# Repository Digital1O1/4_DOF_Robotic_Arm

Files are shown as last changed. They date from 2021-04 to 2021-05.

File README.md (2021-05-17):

# Intention Of 4_DOF_Robotic_Arm Project
1. Take gyroscopic/magnetometer/accelerometer data from an MPU_9250 to calculate the Yaw/Pitch/Roll
2. Use three NRF24l01 Radio frequency development boards to wirelessly transmit data from one microcontroller (Teensy 4) to two other microcontrollers (Wedmos D1 | Arduino Nano)
3. Display the calulated Yaw/Pitch/Roll values that are being transmitted/recieved on their perspective SH1106 OLED display (Recieving/Transmitting)
4. Use one microcontroller that's recieving the transmitted data to control a 3-d printed, 4 Degree of Freedom robotic arm. 



## Bill of Materials (BOM)
1. (2) microcontrollers of your choice. (3) were used (Teensy 4/Arduino Nano/ Wedmos D1) in this instance for reasons explained later in this repo.
3. (2) or (3) NRF24l01 radio frequency development boards
5. A BUNCH of male-female wires
6. (3) 10uF or 100 uF electrolytic capacitors
7. (2) SG-90 servo motors
8. (2) SH1106 OLED displays
9. (1) Push button

# In-depth Explantion of Project
- The user is prompted through the Arduino serial monitor or terminal of their choice if they want to calibrate the MPU_9250. 
    - If the user enters '1' in the serial monitor, the calibration procedure will initiate. 
    - If the user enters '2', they can skip the calibration process completely.
- The MPU_9250 gyroscopic/magnetometer/accelerometer data is sent via __SPI__ to the Teensy 4 in order to calculate the pitch/yaw/roll 
- The calculated values are then displayed on an SH1106 OLED display connected via __I2C__ on the Teensy 4 
- The same calculated values are then transmitted through the nrf24l01 to an Arduino Nano and an Wedmos D1 microcontroller as shown in the figure below.



- The Arduino Nano recieves the transmitted data from the Teensy 4 in order to control the 4-DOF robotic as shown in the screenshot below

 

- The Wedmos D1 displays the recieved data on it's own SH1106 OLED display to give reassurnace that the transmitted data is being recieved from the Teensy 4.

## Kalman Filter
What’s a Kalman Filter?

An algorithm that estimates an unknown variable based on the measurements given over time.

Why use a Kalman Filter?

- The Kalman filter was used to reduce the noise from the gyroscopic/accelerometer/magnetometer data to allow the yaw/pitch/roll angles to be calculated as accurately as possible.

- Kalman filters are also typically used with drones to determine their orientation during flight.

- KEEP IN MIND, the values used for the Kalman filter have NOT been fine tuned’ yet since the majority of the time spent on this project was focused on other aspects of this project; but the values will be fine tuned at a later date.

# What's With All The Folders In The Repo?

Here's a quick run-down 

- I2C_Scanner
  - Used for troubleshooting peripherals that use the I2C communication protocol/bus
  - Peripherals like OLED displays use I2C
  - The 'I2C_Scanner' can be used to determine the address of the OLED display, or any peripheral using I2C.

- NRF Folder
  - Contains all NRF24l01 code
  - Hello World 
    - One microcontroller transmits 'Hello World' while the other microcontroller recieves it and displays it on the serial monitor
  - Transmit_Array | Transmit_Struct
    - As the name implies, the transmitted data can be sent two ways. As an array, or as a struct. In reference to this project, the array method was used
  - ackPayload
    - Two way communication between two microcontrollers
    - To elaborate further :
      - One microcontroller transmits data
      - The other recieves it and sends an 'Acknowledgement' back to the transmitting microcontroller that data was recieved
  
  - Robotic_Arm_V3_NRF_Mesh
    -  Teensy_Transmit_IMU_Data
        - Transmit only the gryo/accel/magometer data to the recieving microcontrollers (Wedmos D1/ Nano)
    - Teensy_Transmitter
      - Gives user the option to calibrate the MPU_9250 or to skip the calibration process
      - Calculate yaw/pitch/roll
      - Display yaw/pitch/roll data on SH1106 OLED display
      - Transmit yaw/pitch/roll datat to Wedmos/Nano microcontrollers
    - Nano_Recieve_Robotic_Arm
      - Recieves transmitted data from Teensy
      - Microcontroller responsible for controlling Robotic Arm
    - Wedmos_Recieve_Robotic_Arm
      - Recieves transmitted data
      - Display transmitted data on SH1106 OLED display

# Why Use Two Microcontrollers to Recieve the Transmitted Data?

The Arduino Nano/Uno has only 32 KB of on-board Flash memory.

When the Servo,RF,and OLED libraries were included in the Arduino Nano/Uno sketch/code, the majority of the Flash memory (~97%) was used which lead to the microcontroller to become unstable and would periodically crash. 

When the same steps were repeated with the Wedmos D1, the RF and OLED libraries together would work fine. 

However when the Servo libraries were included in the sketch/code, the watchdog timer was triggered for some reason and the program wouldn't run.

So rather than troubleshooting why the watchdog timer was being triggered, I took the easy way out of the entire situation and just had the Wedmos D1 display the data being recieved, while the Nano was being used to control the robotic arm and would display the transmitted data via the serial monitor.

# FAQ

- Is the Wedmos D1 needed?
  - Honestly, not really. As mentioned earlier, the sole purpose of the Wedmos D1 was to display the transmitted data from the Teensy.
  - A person really only needs the Teensy (Or a similar development board that has a clock speed greater than 80 Mhz) and the Arduino Uno/Nano to run everything

- Will you re-visit and troubleshoot why the Watchdog timer is being triggered on the Wedmos D1 when the servo library is inlucded with the RF and OLED libraries?
  - It'll depend on the amount of free time I have on my hands since I'm not working on projects in my Github Repository full time

- How will I print out the STL files needed for the Robotic Arm?
  - Contact your local library. Most of them nowadays have a "Maker Space" and SHOULD have 3d-printers that the public can use.

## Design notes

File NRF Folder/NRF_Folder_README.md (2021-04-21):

# Purpose of this folder

To ensure the NRF boards are communicating with one another, upload the sketches/C++ code in the 'Hello World' folder

The other two folders serve as a starting point to send multiple values (floats, ints, ect.) from one microcontroller to another using the NRF2401 RF boards

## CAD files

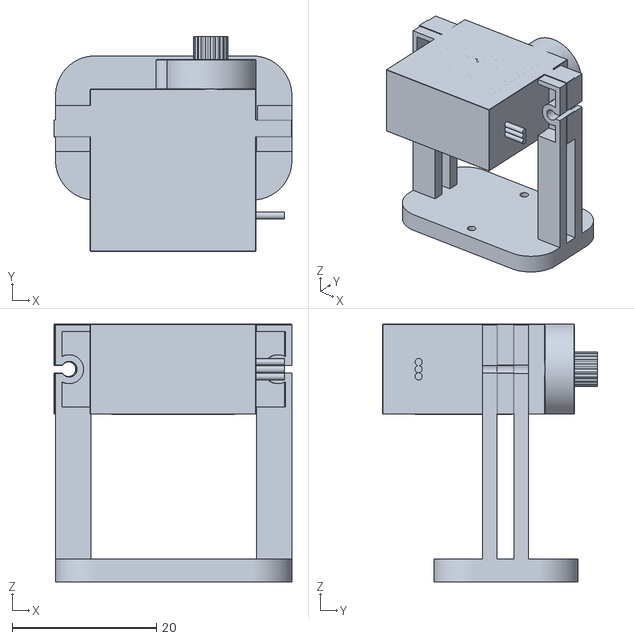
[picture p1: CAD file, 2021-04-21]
STL_Files/Vertical base.stl
33.0 x 29.8 x 35.8

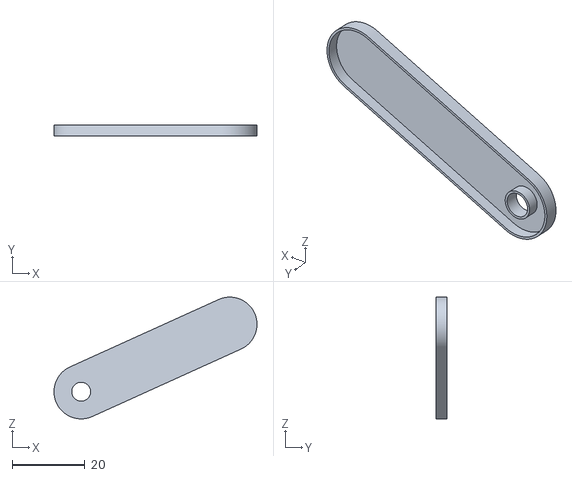
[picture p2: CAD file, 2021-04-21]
STL_Files/Extension Arm.stl
56.0 x 3.00 x 33.6

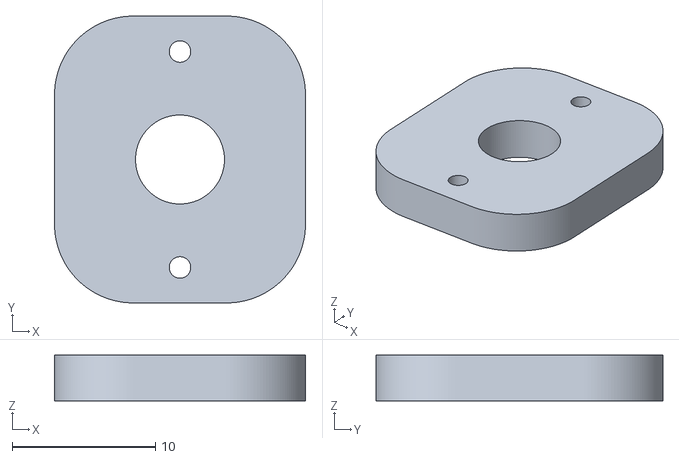
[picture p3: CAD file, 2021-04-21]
STL_Files/Horiztonal base.stl
17.5 x 20.0 x 3.20

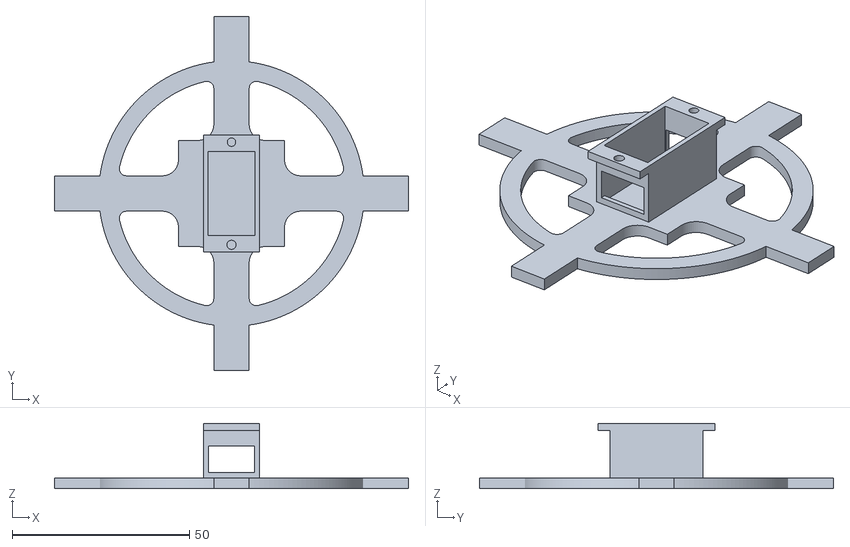
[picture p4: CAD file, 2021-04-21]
STL_Files/Arm_Base.stl
100.0 x 100.0 x 18.5

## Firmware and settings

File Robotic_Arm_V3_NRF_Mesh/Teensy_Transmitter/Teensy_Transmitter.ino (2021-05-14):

/*
   OLED Display using I2C communication BUS

   If using Teensy 4
   SCL = Pin 19
   SDA = Pin 18

*/
#include "MPU9250.h"
#include <Servo.h>
#include "U8g2lib.h"
#include <Wire.h>
#include <nRF24L01.h>
#include <RF24.h>
#include <SPI.h>

#define CE_PIN  7
#define CSN_PIN 8
#define NANO 0
#define WEDMOS 1

U8G2_SH1106_128X64_NONAME_F_HW_I2C OLED(U8G2_R0, /* reset=*/U8X8_PIN_NONE);
MPU9250 IMU(SPI, 10);
Servo x_servo, y_servo;

//---------------------- Variables ----------------------//
const int buttonPin = 2;         // the number of the pushbutton pin
int buttonState = 0;         // variable for reading the pushbutton status
int status, gyro_Calibration_Status,
    accel_Calibration_Status, magn_Calibration_Status,
    map_X, map_Y = 0;
static const float R = 50;                            // Noise covariance (Should be 10) | Higher R --> Filters more, but slower
static const float H = 1.00;                          // Measurement map scalar
static const float Q = 10;                            // Initial estimated covariance
float aX, aY, aZ, gX, gY, gZ, K, P, U_hat_gX, U_hat_gY, U_hat_gZ, U_hat_aX, U_hat_aY, U_hat_aZ, U_hat_mX, U_hat_mY, U_hat_mZ,
      filtered_gX, filtered_gY, filtered_gZ, filtered_aX, filtered_aY, filtered_aZ, gX_bias, gY_bias, gZ_bias,
      aX_bias, aY_bias, aZ_bias, roll, pitch, heading, set_gX_bias, set_gY_bias, set_gZ_bias,
      hxs, hys, hzs, hxb, hyb, hzb, gxb, gyb, gzb, axb, ayb, azb, axs , ays, azs, mag_x, mag_y, yaw,
      mX, mY, mZ, f_ax, filtered_roll, filtered_pitch, filtered_yaw, filtered_mX, filtered_mY, filtered_mZ,
      filtered_mag_x, filtered_mag_y, U_hat_roll, U_hat_pitch, U_hat_yaw = 0;
float sendData[5];
char display_pitch[20], display_roll[20], display_yaw[20], display_map_X[20], display_map_Y[20];

// NRF Stuff
bool radio_result;
const byte numSlaves = 2;
const byte slaveAddress[numSlaves][5] = {
  // each slave needs a different address
  {'R', 'x', 'A', 'A', 'A'},
  {'R', 'x', 'A', 'A', 'B'}
};
RF24 radio(CE_PIN, CSN_PIN); // Create a Radio
float dataToSend[100];
int ackData[2] = { 0, 0}; // to hold the two values coming from the slave
bool newData = false;
//---------------------- Functions ----------------------//
float K_filter_gyro(float &raw_gX, float &raw_gY, float &raw_gZ, float &filtered_gX, float &filtered_gY, float &filtered_gZ)
{
  K = P * H / (H * P * H + R);                        // Current Kalman gain = 0.36
  U_hat_gX = U_hat_gX + K * (raw_gX - H * U_hat_gX);  // Update Estimated values
  U_hat_gY = U_hat_gY + K * (raw_gY - H * U_hat_gY);
  U_hat_gZ = U_hat_gY + K * (raw_gY - H * U_hat_gY);
  P = (1 - K * H) * P + Q;                            // Update Error in Estimate
  filtered_aX = U_hat_aX;
  filtered_aY = U_hat_aY;
  filtered_aZ = U_hat_aZ;
}

float K_filter_accel(float &raw_aX, float &raw_aY, float &raw_aZ, float &filtered_aX, float &filtered_aY, float &filtered_aZ)
{
  K = P * H / (H * P * H + R);                        // Update Kalman Gain | KG == Large --> error in estimate == LARGE error in measurement == Small | KG == Small --> Error im measurement == Large Error in estimate == Small
  U_hat_aX = U_hat_aX + K * (raw_aX - H * U_hat_aX);  // Update Estimated values
  U_hat_aY = U_hat_aY + K * (raw_aY - H * U_hat_aY);
  U_hat_aZ = U_hat_aZ + K * (raw_aZ - H * U_hat_aZ);
  P = (1 - K * H) * P + Q;                            // Update Error in Estimate

  filtered_aX = U_hat_aX;
  filtered_aY = U_hat_aY;
  filtered_aZ = U_hat_aZ;

}

void read_Sensor()
{
  // Read the sensor
  IMU.readSensor();
  aX = IMU.getAccelX_mss();
  aY = IMU.getAccelY_mss();
  aZ = IMU.getAccelZ_mss();
  gX = IMU.getGyroX_rads();
  gY = IMU.getGyroY_rads();
  gZ = IMU.getGyroZ_rads();
  mX = IMU.getMagX_uT();
  mY = IMU.getMagY_uT();
  mZ = IMU.getMagZ_uT();
}


void K_filter(float &raw_aX, float &raw_aY, float &raw_aZ, float &raw_mX, float &raw_mY, float &raw_mZ, float &raw_gX,
              float &raw_gY, float &raw_gZ, float &filtered_aX, float &filtered_aY, float &filtered_aZ,
              float &filtered_gX, float &filtered_gY, float &filtered_gZ, float &filtered_mX, float &filtered_mY, float &filtered_mZ)
{
  K = P * H / (H * P * H + R);                        // Update Kalman Gain | KG == Large --> error in estimate == LARGE error in measurement == Small | KG == Small --> Error im measurement == Large Error in estimate == Small

  //Accelermotor
  U_hat_aX = U_hat_aX + K * (raw_aX - H * U_hat_aX);  // Update Estimated values
  U_hat_aY = U_hat_aY + K * (raw_aY - H * U_hat_aY);
  U_hat_aZ = U_hat_aZ + K * (raw_aZ - H * U_hat_aZ);

  //Gyroscopic
  U_hat_gX = U_hat_gX + K * (raw_gX - H * U_hat_gX);  // Update Estimated values
  U_hat_gY = U_hat_gY + K * (raw_gY - H * U_hat_gY);
  U_hat_gZ = U_hat_gY + K * (raw_gY - H * U_hat_gY);

  //Mag
  U_hat_mX = U_hat_mX + K * (raw_mX - H * U_hat_mX);  // Update Estimated values
  U_hat_mY = U_hat_mY + K * (raw_mY - H * U_hat_mY);
  U_hat_mZ = U_hat_mY + K * (raw_mY - H * U_hat_mY);
  P = (1 - K * H) * P + Q;

  filtered_aX = U_hat_aX;
  filtered_aY = U_hat_aY;
  filtered_aZ = U_hat_aZ;

  filtered_gX = U_hat_gX;
  filtered_gY = U_hat_gY;
  filtered_gZ = U_hat_gZ;

  filtered_mX = U_hat_mX;
  filtered_mY = U_hat_mY;
  filtered_mZ = U_hat_mZ;
}


void K_filter_pitch_roll(float &raw_roll, float &raw_pitch, float &raw_yaw)
{
  K = P * H / (H * P * H + R);                        // Update Kalman Gain | KG == Large --> error in estimate == LARGE error in measurement == Small | KG == Small --> Error im measurement == Large Error in estimate == Small

  U_hat_roll = U_hat_roll + K * (raw_roll - H * U_hat_roll);  // Update Estimated values
  U_hat_pitch = U_hat_pitch + K * (raw_pitch - H * U_hat_pitch);
  U_hat_yaw = U_hat_yaw + K * (raw_yaw - H * U_hat_yaw);

  P = (1 - K * H) * P + Q;

  filtered_roll = U_hat_roll;
  filtered_pitch = U_hat_pitch;
  filtered_yaw = U_hat_yaw;
}

void plot_serial_data()
{
  Serial.print(roll);  Serial.print(',');
  Serial.print(pitch); Serial.print(',');
  Serial.print(yaw); Serial.print(',');
  Serial.print(filtered_roll); Serial.print(',');
  Serial.print(filtered_pitch); Serial.print(',');
  Serial.println(filtered_yaw);
}
void display_serial_data()
{
  Serial.print("Roll : "); Serial.print(roll);
  Serial.print("\tPitch : "); Serial.print(pitch);
  Serial.print("\tYaw : "); Serial.print(yaw);
  Serial.print("\t Filtered Roll : "); Serial.print(filtered_roll);
  Serial.print("\tFiltered Pitch : "); Serial.print(filtered_pitch);
  Serial.print("\tFiltered Yaw  : "); Serial.println(filtered_yaw);
}
void setup()
{
  // Serial communication
  Serial.begin(115200);

  // Button stuff
  pinMode(buttonPin, INPUT);

  // OLED stuff
  OLED.setI2CAddress(0x3D * 2);
  OLED.begin();
  OLED.setFont(u8g2_font_7x13B_mr);

  // RF stuff
  radio.begin();

  //speed  RF24_250KBPS for 250kbs, RF24_1MBPS for 1Mbps, or RF24_2MBPS for 2Mbps
  radio.setDataRate( RF24_250KBPS );

  //Ack payloads are a handy way to return data back to senders without manually changing the radio modes on both units.
  radio.enableAckPayload();

  /*
     Set the number and delay of retries upon failed submit.
     Syntax : setRetries(delay,count);
     delay How long to wait between each retry, in multiples of 250us, max is 15. 0 means 250us, 15 means 4000us.
     count How many retries before giving up, max 15
  */
  radio.setRetries(3, 5); // delay, count


  Serial.println("-------------[ SERIAL COMMUNICATION ESTABLISHED ]-------------\n");
  Serial.println("-------------[ CHECKING IMU ]-------------\n");

  // Start communication with IMU and estimates/removes gyro bias from sensor data | This has to be first for some reason
  status = IMU.begin();
  if (status < 0)
  {
    Serial.println("IMU initialization unsuccessful");
    Serial.println("Check IMU wiring or try cycling power");
    Serial.print("Status: ");
    Serial.println(status);
    while (1) {}
  }
  else
  {
    Serial.println("-------------[ IMU IS OPERATIONAL ]-------------\n");
    OLED.drawStr(40, 10, "Check");
    OLED.drawStr(40, 30, "Serial");
    OLED.drawStr(40, 50, "Monitor");
    OLED.sendBuffer();  // transfer internal memory to the display
    OLED.clearBuffer(); // clear the internal memory
  }

  Serial.println("Enter '1' to calibrate | Enter '2' to skip calibration");
  while (true)
  {
    buttonState = digitalRead(buttonPin);

    if ((Serial.available() > 0) || (buttonState == HIGH))
    {
      char user_input = Serial.read();
      if (user_input == '1')
        //switch (user_input)
      {
        //case '1':
        {
          // =============================================== CALIBRATION STUFF STARTS HERE =============================================== //

          //---------------------------------------------------- [ CALIBRATE GYRO ] ----------------------------------------------------//
          /*
              -- GYRO --
              The gyro bias is automatically estimated during the begin() function, then removed from sensor measurements
              IMU.calibrateGyro(); --> Will re-estimate gyro bias and remove new bias from future measurements
              NEEDS TO BE STATIONARY
              Function should return POSITIVE value on succcess | NEGATIVE value on failure
          */

          Serial.println("===============================================================================================");
          Serial.println("\nCALIBRATE GYROSCOPE...");

          // Wait for user input
          while (true)
          {
            // Checks serial monitor for incoming data
            if (Serial.available() > 0)
            {
              // If user presses 'ENTER' break out of while loop
              if (Serial.read() == '\n')
              {
                Serial.println("\nPlace IMU sensor on solid surface and DON'T TOUCH IT");
                delay(2000);

                Serial.println("\nCALIBRATION STARTING IN...\n");
                break;
              }
            }
            //Serial.print(".");
            delay(2000);
          }
          // Countdown timer
          for (int i = 5; i > 0; i--)
          {
            Serial.print(i);
            Serial.println("...");
            delay(1000);
          }
          Serial.println("\nCALIBRATION IN PROGRESS");

          if (IMU.calibrateGyro() == true)
          {
            Serial.println("\nCALIBRATION COMPLETE\n");

            // "Grab" bias values
            gxb = IMU.getGyroBiasX_rads();
            gyb = IMU.getGyroBiasY_rads();
            gzb = IMU.getGyroBiasZ_rads();

            // Set bias values
            IMU.setGyroBiasX_rads(gxb);
            IMU.setGyroBiasY_rads(gyb);
            IMU.setGyroBiasZ_rads(gzb);

            // Print out bias values
            Serial.println("---- GYRO BIAS VALUES SET TO ----\n");
            Serial.print("GXB : "); Serial.print(gxb); Serial.print(',');
            Serial.print(" GYB : "); Serial.print(gyb); Serial.print(',');
            Serial.print(" GZB : "); Serial.println(gzb);
          }
          //---------------------------------------------------- [ CALIBRATE ACCELEROMOTOR ] ----------------------------------------------------//

          /*
              -- ACCEL --
              int calibrateAccel() --> estimate bias/scale factor needed to calibrate accelerometer

              Works on one axis at a time, needs to run on all 6 sensor orientation
              After it collects enough sensor data, it'll estimate the bias/scale factor for all three accelerometer channels and apply the corrections to measured data
              Accel calibration needs to be performed ONCE on IMU
              Both get/set functions can be used to retrieve estimated bias/scale factors and use them during future power cycles or operations with IMU
          */
          Serial.println("===============================================================================================\n");
          Serial.println("\n-------------[ CALIBRATING ACCELEROMOTOR ]-------------\n");
          delay(1200);
          Serial.println("Orientate IMU to desiered INITAL position to calibrate all SIX axes\n");
          delay(1200);
          Serial.println("To initiate ACCELEROMOTOR calibration press [ ENTER ]...");
          // Wait for user input
          while (true)
          {
            // Checks serial monitor for incoming data
            if (Serial.available() > 0)
            {
              // If user presses 'ENTER' break out of while loop
              if (Serial.read() == '\n')
              {
                Serial.println("\nCALIBRATION IN PROGRESS...");
                break;
              }
            }
            Serial.print(".");
            delay(1000);

          }
          // This is where the actual calibration takes place. Orientate the IMU sensor in SIX different directions AND MAKE SURE IT'S STABLE
          for (int n = 1; n <= 6; n++)
          {
            Serial.print("\nCurrent calibration iteration(s) : ");
            Serial.print(n); Serial.println(" \\ 6\n");

            // Countdown timer
            for (int i = 5; i > 0; i--)
            {
              Serial.print(i);
              Serial.println("...");
              delay(1000);
            }
            Serial.println("\n-------------[ CALIBRATION IN PROGRESS ]-------------");

            IMU.calibrateAccel();

            Serial.println("\n-------------[ Change IMU posistion ]-------------");
          }
          Serial.println("\n-------------[ Calibrating accelerometer COMPLETE ]-------------\n");


          // Get Scale factor values
          // Scale factors are the ratio between the measured output and the change in the 'sense' input
          // More info about scale factors can be found here : https://www.edn.com/evaluating-inertial-measurement-units/
          axs = IMU.getAccelScaleFactorX();
          ays = IMU.getAccelScaleFactorY();
          azs = IMU.getAccelScaleFactorZ();

          // Biased Factors
          axb = IMU.getAccelBiasX_mss();
          ayb = IMU.getAccelBiasY_mss();
          azb = IMU.getAccelBiasZ_mss();

          // Display scale/bias values
          Serial.println("\n-------------[ SCALE FACTORS ]-------------\n");

          Serial.print("X_Scale Factor : "); Serial.print(axs);
          Serial.print(" Y_Scale Factor : "); Serial.print(ays);
          Serial.print(" Z_Scale Factor : "); Serial.println(azs);

          Serial.println("\n-------------[ BIAS VALUES]-------------\n");

          Serial.print("X_Biased : "); Serial.print(axb);
          Serial.print(" Y_Biased : "); Serial.print(ayb);
          Serial.print(" Z_Biased : "); Serial.println(azb);

          // Store scale/bias values into an array
          const float accelBias[3] = {axb, ayb, azb};
          const float accelFactor[3] = {axs, ays, azs};

          // Set the scale/bias values accordingly
          Serial.println("\n-------------[ IMU VALUES SET TO]-------------\n");
          IMU.setAccelCalX(accelBias[0], accelFactor[0]);
          IMU.setAccelCalY(accelBias[1], accelFactor[1]);
          IMU.setAccelCalZ(accelBias[2], accelFactor[2]);

          // Display
          Serial.print("Ax_Bias : "); Serial.print(accelBias[0]);  Serial.print(" | Ax_Accel : "); Serial.println(accelFactor[0]);
          Serial.print("Ay_Bias : "); Serial.print(accelBias[1]);  Serial.print(" | Ay_Accel : "); Serial.println(accelFactor[1]);
          Serial.print("Az_Bias : "); Serial.print(accelBias[2]);  Serial.print(" | Az_Accel : "); Serial.println(accelFactor[2]);
          delay(3000);

          Serial.println("\n===============================================================================================\n");
          delay(2000);

          //---------------------------------------------------- [ CALIBRATE MAGNETOMETER ] ----------------------------------------------------//

          Serial.println("\nPress [ ENTER ] to calibrate megnetometer...");

          // Calibration won't start until user inputs 'ENTER' in the serial monitor
          while (true)
          {
            // Checks serial monitor for incoming data
            if (Serial.available() > 0)
            {
              // If user presses 'ENTER' break out of while loop
              if (Serial.read() == '\n')
              {
                Serial.println("\n\n-------------[ CALIBRATING MAGNETOMETER WILL TAKE ~60-80 SECONDS TO COMPLETE...]-------------");
                delay(1500);
                Serial.println("\n-------------[ SLOWLY AND CONTINUOUSLY MAKE A FIGURE 8 MOTION DURING CALIBRATION ]-------------");
                delay(2000);

                Serial.println("\nCALIBRATION STARTING IN...\n");
                break;
              }
            }
            Serial.print(".");
            delay(1000);
          }

          // Countdown timer
          for (int i = 5; i > 0; i--)
          {
            Serial.print(i);
            Serial.println("...");
            delay(1000);
          }

          if (IMU.calibrateMag() == true)
          {
            // Gather magnetometer bias/scale factors
            hxb = IMU.getMagBiasX_uT();
            hyb = IMU.getMagBiasY_uT();
            hzb = IMU.getMagBiasZ_uT();
            hxs = IMU.getMagScaleFactorX();
            hys = IMU.getMagScaleFactorY();
            hzs = IMU.getMagScaleFactorZ();

            // Display bias/scale factors
            Serial.println("\nCALIBRATION COMPLETE\n");
            Serial.println("---- MAG BIAS VALUES ----\n");
            Serial.print("X_Bias : "); Serial.print(hxb); Serial.print(',');
            Serial.print(" Y_Bias : "); Serial.print(hyb); Serial.print(',');
            Serial.print(" Z_Bias : "); Serial.println(hzb);
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
void loop()
{
  //https://howtomechatronics.com/tutorials/arduino/how-to-track-orientation-with-arduino-and-adxl345-accelerometer/
  //https://www.nxp.com/files-static/sensors/doc/app_note/AN3461.pdf

  // open the writing pipe with the address of a slave
  radio.stopListening();

  // Only one pipe can be open at once, but you can change the pipe you'll listen to.
  // Do not call this while actively listening.
  // Remember to stopListening() first.
  radio.openWritingPipe(slaveAddress[NANO]);
  radio.openWritingPipe(slaveAddress[WEDMOS]);

  // Gather sensor data from IMU
  read_Sensor();

  // Apply Kalman Filter to IMU values
  K_filter(aX, aY, aZ, mX, mY, mZ, gX, gY, gZ, filtered_aX, filtered_aY,
           filtered_aZ, filtered_gX, filtered_gY, filtered_gZ, filtered_mX, filtered_mY, filtered_mZ);

  // Calculate Roll and Pitch (rotation around X-axis, rotation around Y-axis)
  //https://howtomechatronics.com/tutorials/arduino/how-to-track-orientation-with-arduino-and-adxl345-accelerometer/
  //https://www.nxp.com/files-static/sensors/doc/app_note/AN3461.pdf

  roll = atan(aY / sqrt(pow(aX, 2) + pow(aZ, 2))) * 180 / PI;
  pitch = atan(-1 * aX / sqrt(pow(aY, 2) + pow(aZ, 2))) * 180 / PI;
  mag_x = mX * cos(pitch) + mY * sin(roll) * sin(pitch) + mZ * cos(roll) * sin(pitch);
  mag_y = mY * cos(roll) - mZ * sin(roll);
  yaw = 180 * atan2(-mY, mX) / M_PI;

  K_filter_pitch_roll(roll, pitch, yaw);
  //plot_serial_data();
  //display_serial_data();

  map_X = map(filtered_roll, -80, 80, 0, 180);
  map_Y = map(filtered_pitch, -77, 82, 0, 180);

  x_servo.write(abs(map_X));
  y_servo.write(abs(map_Y));

  //Roll = -80 80
  //Pitch = -77 82

  sendData[0] = pitch;
  sendData[1] = yaw;
  sendData[2] = roll;
  sendData[3] = map_X;
  sendData[4] = map_Y;

  // SEE HOW MUCH DATA CAN BE WRITTEN AT ONE TIME
  radio_result = radio.write( &dataToSend, sizeof(dataToSend) );

  // Write data
  if (radio_result)
  {
    Serial.print("Pitch : "); Serial.print(sendData[0]);
    Serial.print("\tRoll : "); Serial.print(sendData[1]);
    Serial.print("\tYaw: "); Serial.print(sendData[2]);
    Serial.print("\tMap_X : "); Serial.print(sendData[3]);
    Serial.print("\tMax_Y : "); Serial.println(sendData[4]);
    if ( radio.isAckPayloadAvailable() )
    {
      radio.read(&ackData, sizeof(ackData));
      newData = true;
    }
    else
    {
      Serial.println("Acknowledge but no data ");
    }
  }
  else
  {
    Serial.println("Trasnmission FAILED");
  }
  Serial.println();

  /*
    Serial.print("Pitch : "); Serial.print(sendData[0]);
    Serial.print("\tRoll : "); Serial.print(sendData[1]);
    Serial.print("\tYaw: "); Serial.print(sendData[2]);
    Serial.print("\tMap_X : "); Serial.print(sendData[3]);
    Serial.print("\tMax_Y : "); Serial.println(sendData[4]);
  */
  // OLED STUFF
  dtostrf(roll, 2, 2, display_roll);
  dtostrf(pitch, 2, 2, display_pitch);
  dtostrf(yaw, 2, 2, display_yaw);
  dtostrf(map_X, 2, 2, display_map_X);
  dtostrf(map_Y, 2, 2, display_map_Y);

  radio.write(sendData, sizeof(sendData)); // sizeof(data) == 20 bytes

  OLED.drawStr(5, 10, "Pitch : ");
  OLED.drawStr(80, 10, display_pitch);

  OLED.drawStr(5, 22, "Roll : ");
  OLED.drawStr(80, 22, display_roll);

  OLED.drawStr(5, 35, "Yaw : ");
  OLED.drawStr(80, 35, display_yaw);

  OLED.drawStr(5, 52, "Map X : ");
  OLED.drawStr(80, 52, display_map_X);

  OLED.drawStr(5, 64, "Map Y : ");
  OLED.drawStr(80, 64, display_map_Y);

  OLED.sendBuffer();  // transfer internal memory to the display
  OLED.clearBuffer(); // clear the internal memory

  /*
    OLED.drawStr(5, 10, "Pitch : ");
    OLED.drawStr(80, 10, display_pitch);

    OLED.drawStr(5, 35, "Roll : ");
    OLED.drawStr(80, 35, display_roll);

    OLED.drawStr(5, 60, "Yaw : ");
    OLED.drawStr(80, 60, display_yaw);
    OLED.sendBuffer();  // transfer internal memory to the display
    OLED.clearBuffer(); // clear the internal memory
    Taking the gyroscopic, accelerator, magometer data from a calibrated MPU_9250 to calculate the yaw, pitch and roll which is then sent via a wireless communication protocol to control a 4-Degree-Of-Freedom robotic arm, or other peripherals such as rovers, drones, ect.

  */

  delay(50);
}

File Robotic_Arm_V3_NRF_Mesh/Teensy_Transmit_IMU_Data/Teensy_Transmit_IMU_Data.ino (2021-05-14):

#include "MPU9250.h"
#include <SPI.h>
#include <nRF24L01.h>
#include <RF24.h>

#define CE_PIN   7
#define CSN_PIN 8

const byte numSlaves = 2;
// each slave needs a different address
const byte slaveAddress[numSlaves][5] =
{
  {'R', 'x', 'A', 'A', 'A'},
  {'R', 'x', 'A', 'A', 'B'}
};

RF24 radio(CE_PIN, CSN_PIN); // Create a Radio
// an MPU9250 object with the MPU-9250 sensor on SPI bus 0 and chip select pin 10
MPU9250 IMU(SPI, 10);
int status;
float axb, ayb, azb, axs, ays, azs,
      aX, aY, aZ, gX, gY, gZ,
      gxb, gyb, gzb, mX, mY, mZ = 0;


int ackData[2] = { -1, -1}; // to hold the two values coming from the slave
float sendData[100];
bool radio_result;

void printData()
{
  // Print data
  Serial.print(sendData[0]); Serial.print('\t');
  Serial.print(sendData[1]); Serial.print('\t');
  Serial.print(sendData[2]); Serial.print('\t');
  Serial.print(sendData[3]); Serial.print('\t');
  Serial.print(sendData[4]); Serial.print('\t');
  Serial.print(sendData[5]); Serial.print('\t');
  Serial.print(sendData[6]); Serial.print('\t');
  Serial.print(sendData[7]); Serial.print('\t');
  Serial.println(sendData[8]);
}

void setup()
{
  // Establish Serial Communication
  Serial.begin(115200);
  Serial.println("-------------[ SERIAL COMMUNICATION ESTABLISHED ]-------------\n");
  Serial.println("-------------[ CHECKING IMU ]-------------\n");

  // Check if IMU is operational
  status = IMU.begin();
  if (status < 0) {
    Serial.println("IMU initialization unsuccessful");
    Serial.println("Check IMU wiring or try cycling power");
    Serial.print("Status: ");
    Serial.println(status);
    while (1) {}
  }
  else
  {
    Serial.println("-------------[ IMU IS OPERATIONAL ]-------------\n");
  }

  if (radio.begin())
  {
    radio.setDataRate( RF24_250KBPS );
    radio.setPALevel(RF24_PA_MIN);
    radio.enableAckPayload();
    radio.setRetries(3, 5); // delay, count
    radio.printDetails();
    delay(5000);
    // radio.openWritingPipe(slaveAddress); -- moved to loop()
    Serial.println("-------------[ RF COMMUNICATION ESTABLISHED ]-------------\n");
  }
  else
  {
    Serial.println("-------------[ RF COMMUNICATION FAILED ]-------------\n");
  }

}

void loop()
{
  // Iterate through slave devices in RF mesh
  for (int i = 0; i < numSlaves; i++)
  {
    // Read IMU Data
    IMU.readSensor();
    aX = (IMU.getAccelX_mss());
    aY = (IMU.getAccelY_mss());
    aZ = (IMU.getAccelZ_mss());
    gX = (IMU.getGyroX_rads());
    gY = (IMU.getGyroY_rads());
    gZ = IMU.getGyroZ_rads();
    mX = (IMU.getMagX_uT());
    mY = (IMU.getMagY_uT());
    mZ = (IMU.getMagZ_uT());

    // Store IMU data
    sendData[0] = aX;
    sendData[1] = aY;
    sendData[2] = aZ;
    sendData[3] = gX;
    sendData[4] = gY;
    sendData[5] = gZ;
    sendData[6] = mX;
    sendData[7] = mY;
    sendData[8] = mZ;
    
    // open the writing pipe with the address of a slave
    radio.stopListening();


    // Only one pipe can be open at once, but you can change the pipe you'll listen to.
    // Do not call this while actively listening.
    // Remember to stopListening() first.
    radio.openWritingPipe(slaveAddress[i]);


    radio_result = radio.write( &sendData, sizeof(sendData) );

    if (radio_result)
    {
      printData();
      if ( radio.isAckPayloadAvailable() )
      {
        //printData();
        radio.read(&ackData, sizeof(ackData));
      }
      else
      {
        //Serial.println("Acknowledge but no data ");
      }
    }
    else
    {
      Serial.println("Transmission failed");
    }
    //acknowledge_Data();
    //Serial.println();

  } // End of 'for(int i = 0; i < number_Slaves; i++)'
  delay(100);
}
